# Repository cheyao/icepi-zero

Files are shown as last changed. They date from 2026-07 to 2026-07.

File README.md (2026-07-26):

# Icepi Zero - The portable FPGA development board



| Get your own on: | [**Crowd Supply**](https://www.crowdsupply.com/icy-electronics/icepi-zero) | [**Elecrow**](https://www.elecrow.com/icepi-zero.html) |
| --- | --- | --- |

If you are a student/educational institute, send me an email at `cyao _at_ duck.com` and I'll give an educational discount of $65!

We also got a [Discord server](https://discord.gg/vzrqfhcvWr)! Feel free to ask any questions here.

## What is the Icepi Zero?

The Icepi Zero is an FPGA development board in the popular Raspberry Pi Zero form factor. It carries a Lattice ECP5 25F, enabling powerful designs while keeping a small portable size. It also has a GPDI mini (General Purpose Display Interface, same as the one on the Pi Zero) port allowing easy digital video output.



## Why Icepi Zero?

Currently most powerful FPGA boards on the market are expensive and bulky.

I've always wanted a low-cost portable FPGA with video output to make my own CPU, but there isn't any on the market.

The Icepi Zero aims to fix this. Carrying a powerful ECP5 FPGA on a small Raspberry Pi Zero form factor, it is the ultimate portable solution for FPGA development. Additionally packing a GPDI mini port and 3 USB-C ports, it allows interfacing with multiple external I/O devices.

Icepi Zero is for everyone: Students can use it to learn about the internals of modern processors. Gamers can use it to emulate old hardware. Programmers can use it to test their code on multiple architectures.


<sub>Oberon running on Icepi Zero</sub>

Icepi Zero also has an on-board USB to JTAG converter, so no external programmers are needed.

Moreover Icepi Zero is fully open-source, no strings attached. Learn from the design! ([OSHWA cerified FR000026](https://certification.oshwa.org/fr000026.html)).



## Features

- Raspberry Pi Zero form factor
- Lattice ECP5U FPGA:
    - 24k LUT
    - 112 KiB of RAM
- One MiniGPDI connector (it's HDM- but I don't have the money to buy a license...)
- Three USB-C Ports
- 256Mbit 166MHz SDRAM
- MicroSD card slot
- On-board USB to JTAG and UART converter
- 50MHz external oscillator
- 128 Mbit of flash
- 4 user LEDs
- 2 user buttons

This powerful configuration allows the PCB to be used in numerous ways, including real time video processing, hardware AI acceleration and prototyping of ASICs. 

## Emulation

Over the course of multiple weeks, multiple emulation cores have been ported over, such as the [Oberon](https://github.com/cheyao/oberon), [Apple I](https://github.com/cheyao/apple-one) and the [Acorn Atom](https://github.com/cheyao/acorn_atom)! The Icepi Zero allows you to take cycle accurate replicas of your favourite systems in your pocket.


<sub>Apple I running on the Icepi</sub>


<sub>Acorn Atom running on the Icepi</sub>

## Learning

It is also supported by icestudio (custom fork: https://github.com/cheyao/icestudio), allowing easy access for beginners.



## Usage

Check out the `gateware` folder for example code and compilation instructions!

If you want to order this board, it uses a 1.2mm/1.6mm PCB with JLC04121H-7628 Stackup. Gerbers are in the `production` folder in the `hardware` directory.

For the PCB, the smallest component size is 0201 for 27 Ohm resistors on the USB-C datalines. But if you want only 0402 components, just delete those 0201 resistors and you will be fine.

NOTE: If you fabbed v1.1 before 01/06, the pins of the USB pullups and LED0 is different - check your gerbers.



[View PCB online](https://kicanvas.org/?github=https%3A%2F%2Fgithub.com%2Fcheyao%2Ficepi-zero%2Ftree%2Fmain%2Fhardware%2Fv1.2)

## Acknowledgments

This project was inspired by the [ulx3s](https://github.com/emard/ulx3s), huge props to the ulx3s team for making such a good board!

## Contact

If there is any questions DM `cyao.` or join the [discord server](https://discord.gg/vzrqfhcvWr)! Feel free to ask any questions here. Mail is also accepted at `cyao _at_ duck.com`. :)

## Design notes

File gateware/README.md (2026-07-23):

# Icedev Zero Firmware

## Table of Contents
- [Toolchain Setup](#toolchain-setup)
    - [Open Source Toolchain](#option-1-open-source-toolchain)
    - [Lattice Diamond](#option-2-lattice-diamond-ide)
- [Building Demos](#how-to-build-the-demos)
- [Flashing board](#how-to-flash)
- [Pinout](#pinout)
- [Linux on Litex SoC](#litex-soc)
- [More resources](#other-examples)

Welcome to the firmware folder! You can find numerous examples here:

- `blinky`: Classic LED counter!
- `counter`: Counter using the button as input :D
- `uart`: Uart transmission example
- `dvi`: GPDI example
- `usb`: USB examples
    - `usbmouse`: Shows a GPDI screen with an controllable mouse
- `third-party`: Third party verilog code
    - `memtest`: Memory tester w/ hdmi output! Pressing the button increases skew, middle row displays memory test cout, bottom row displays the number of bad memory reads.

## Toolchain setup

### Option 1: Open source toolchain

Download the latest build of the [OSS CAD Suite](https://github.com/YosysHQ/oss-cad-suite-build/releases/).

Unzip it anywhere and set shell command search path:
```
Linux              : export PATH=[path-to-bin]:$PATH
MacOS              : export PATH=[path-to-bin]:$PATH
Windows Powershell : $ENV:PATH = "[path-to-bin];" + $ENV:PATH
Windows cmd.exe    : PATH=[path-to-bin];%PATH%
```

### Option 2: Lattice Diamond IDE

To use the Diamond IDE, you must first request a license. (Free for individuals.)

Go to the [licensing page](https://www.latticesemi.com/Support/Licensing/DiamondAndiCEcube2SoftwareLicensing/DiamondFree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) and create an account. Then copy your device's MAC address, remove all colons and enter it into the "Host NIC" field. Click "Generate License". You should receive a license in your email after a few minutes.

After that, go to Diamond IDE's [download page](https://www.latticesemi.com/LatticeDiamond), install it following their instructions and select the license file when prompted.

You can now use Diamon IDE to create programs and flash it onto your Icepi with openFPGALoader!

Read more detailed instructions in the `DIAMOND.md` file.

## How to build the demos

Just `cd` into the directories, and type `make`!

- `make` runs `make debug`
- `make debug` installs the program to chip (bitstream is lost on power loss)
- `make install` installs the program to flash (bitstream is retained on power loss)
- `make install-bitstream` installs the `bitstream.bit` file to flash without rebuilding
- `make build` builds the bitstream (bitstream is retained on power loss)
- `make clean` deletes all the temporary files

## Make your own!

Just copy the `icepi-zero.lpf` and `Makefile` to the root of your directory, call your main module `top`, and you are good to go!

## How to flash

---
> An example bitstream file exists in the [documentation](../documentation/) folder.

There are two ways of using openFPGALoader to flash the board. The first one is via the command line, second via webusb on a browser.

#### Command Line

The following command is used to flash the development board

```zsh
openFPGALoader -cft231X --pins=7:3:5:6 bitstream.bit
```

You can also add the `--write-flash` flag to permanantly write the bitstream to flash, this way the bitstream file will be saved even when the board powers down.

Note: If you use the newest version of openFPGALoader, it supports the `-b icepi-zero` flag that can replace `-cft231X --pins=7:3:5:6`.

#### Browser

Alternatively, you can use the web version of openFPGALoader on Chrome: [https://ofl.trabucayre.com/](https://ofl.trabucayre.com/). (It won't work on Firefox as webusb is only supported by Chrome)

If you are on Windows, you must first install [Zadig](https://zadig.akeo.ie/), and change the USB driver for the FTDI chip to WinUSB: (Not needed on Linux)

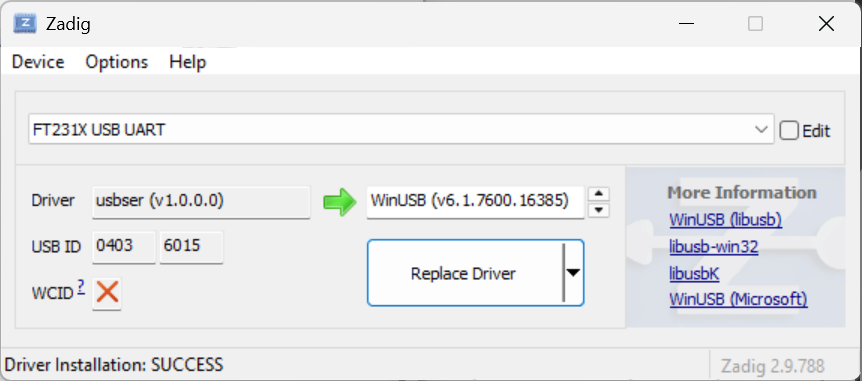
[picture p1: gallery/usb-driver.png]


Then, open the webpage and select "Default" as the cable and "icepi-zero" as the board, upload your .bit file and press Program.



Then select "FT231X USB UART" from the popup menu:



Now your board should be flashed! Happy hacking.

> Getting an error when flasing? Check out the [openFPGALoader troubleshooting](https://trabucayre.github.io/openFPGALoader/guide/troubleshooting.html) page.

## Pinout

The GPIO pinout is exactly the same as a [Pi Zero](https://pinout.xyz/):



You can find the name of rest of the I/O pins in `icepi-zero.lpf`:

- `gpio[27:0]`: gpio pins
- `led[4:0]`: User LEDs
- `button`: User button
- `gpdi_dp[3:0]`: GPDI interface
- `sdram_*`: SDRam interface
- `flash_*`: Flash interface
- `sd_*`: SDCard interface
- `usb_*`: FTDI/USB ports (UART/USB)
- `tp[1:0]`: Test points

Debug pins are distrubuted as the follwing picture shows:



## LiteX SoC

You can run a VexRiscv CPU (and Linux) on the Icepi Zero using [Litex](https://github.com/enjoy-digital/litex), @oliver408i wrote an [awesome guide](https://github.com/oliver408i/icepi-zero-litex) on how to use it!

## Other examples

This board is already supported by [apio](https://github.com/FPGAwars/apio/) and [icestudio](https://github.com/FPGAwars/icestudio)'s development branch. The board should be supported on stable in the next release.

The [litex-boards](https://github.com/litex-hub/litex-boards) also supports the Icepi Zero, while [linux-on-litex-vexriscv](https://github.com/litex-hub/linux-on-litex-vexriscv) has an pr open. (Forgot to open it last month, opps!)

For 1024x600 60Hz video output with audio, check out @danodus's awesome implementation: [https://github.com/danodus/ecp5_hdmi_audio_video](https://github.com/danodus/ecp5_hdmi_audio_video)

And here are some retro ports:

- [Commodore 64](https://github.com/m1nl/icepi-zero-c64) by @m1nl
- [Oberon](https://github.com/cheyao/oberon)
- [Port of Acorn Atom](https://github.com/cheyao/acorn_atom)
- [Apple 1 Emulator](https://github.com/alangarf/apple-one)
- [Sega Master System](https://github.com/cheyao/sega-sms)
- [Port of Silice](https://github.com/sylefeb/Silice/) (Check out the projects folder - it's full of interesting programs)
- [NES](https://github.com/m1nl/icepi-zero-nes/) implemented by [@m1nl](https://github.com/m1nl)

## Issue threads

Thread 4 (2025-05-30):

Hardware version 1.1 shows 1.0 on the silkscreen

cdwijs, 2025-05-30:
I've opened icepi-zero/hardware/v1.1/icepi-zero.kicad_pro in kicad:

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

In the 3d viewer, I see v1.0. That should have been v1.1:

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

cheyao, 2025-05-30:
Fixed!

Closed 2025-05-30.

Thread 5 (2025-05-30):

Testpins are not labeled

cdwijs, 2025-05-30:
On the back of the PCB, there are testpins. These are not labeled on the silkscreen:

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

They are documented in the names of the PCB traces:

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

Can the testpin names be added to the silkscreen?
Is this something to add to the readme?

cheyao, 2025-05-30:
I'd prefer to keep them unlabeled, since it'll be ugly and well testpoints are for testing purposes and you will already have the project open.

cdwijs, 2025-06-01:
I agree it can be ugly on the silkscreen itself.
I don't agree I already have the project open in all use cases. It would be nice if I can see the location of the test pins without having to run KiCad. When the two screenshots I've posted are added to a readme.md, I only need a web browser, so I can check it on a phone or tablet.

cheyao, 2025-06-01:
Oh right! I didn't see that they were marked on the pictures. I'll add them to the readme in the firmware directory soon

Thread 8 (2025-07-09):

Same iBom for all versions

Menkveld-24, 2025-07-09:
Hey as I was assembling I noticed that the iBom for all versions is the same (v1.0)

cheyao, 2025-07-09:
Oh that's my bad! I haven't re-generated the iboms since forever because I never used them :P

I'll just regenerated them all. There shouldn't be any big changes though - in between versions noramly only 1-2 connections are changed, but they force me to bump up the version number.

PS. If you ordered v1.3, I haven't added the lpf yet - the only change is that pin M1 and M2 is swapped. I am still not sure if this was needed and I am currently emailing with Lattice

Closed 2025-07-18.

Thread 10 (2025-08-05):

Is it possible to add a highspeed interface such as USB ULPI?

long-pham, 2025-08-05:
I suggest adding a highspeed interface such as:
- USB3343
- USB 3.0 with SerDes supported by Luna
- pcie if possible

cheyao, 2025-08-06:
Great ideas! I've looked into these a bit and I must say that PCIe would be impossible, because there isn't any place for such a connector on the pcb ;p

USB 3.0 (Assuming you are referring to SS) is equally not possible, since there isn't any space for a 3.0 connector :<

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

I'll have a look to the USB3343 though! Maybe I'll find somewhere to fit one :)

Closed 2025-08-17.

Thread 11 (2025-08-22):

Some sugestions for icepi-zero

goran-mahovlic, 2025-08-22:
Hi cheyao,

I have noticed you have lunched campaign and it looks it will be quite successful one!
So I wanted to congratulate you! You have really nice looking board there.

I really hope you will be able to produce those boards and get at least something out of it as from my perspective it is bit under priced for CS.

ECP is sometimes hard to get, but sometimes like now on LCSC there are limited number of ECP5 available for lower price.
I am mostly buying from Mouser or directly from Lattice over Arrow.
I always check ECP5 price on Octopart and get some average from verified sellers.
There is always marker in CN that offers discounted ECP5 but most of them are recycled and that is good, but then you need to count that some will not work.

In any way did not contact you abut that, but I have noticed few things that I can explain and you missed copy from ULX3S.

First is that ECP5 had some rules about power supply starting, and that can be really bad if not respected.
Like it can no boot, but it can enter in some strange mode and heath like crazy, and eventually die!

That is why emard added 100pF to the power supply's - power up sequence is in datasheet so make sure you read it and try to adjust it as you may face problems when many boards are produced and that will be late to fix.
You can always have at least placeholder for that cap that is doing ramp up.

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

Second is that We added I2C and some pins as we tough we could get HDMI IN - but that never happened.
So we do not even use that I2C chip - it is useful if you want to ask monitor what resolutions does support, but we mostly so not do that we just push picture out...

Zener diode is needed here as if you do not have it you will get 5V on this pin that goes into ECP5 and that is not good.

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

And one more
In my opinion your your 400mA inductors will not be adequate - specially for 3.3V and for other voltages you will need to check maximum current ECP5 will drain once you get bigger design inside.

And for 3.3V you need to calculate ECP5 all logic that works on 3.3V but also on people that will put some logic on HAT and use 3.3V if available.

In my designs I like to avoid using GND layers for Signal - but I see you are using them for JTAG that is not used often so it will probably be fine.

I think for now that is all I have noticed if I find more will let you know.

I am mostly available on Radiona discord so feel free to join -> https://discord.gg/S2CVqWMC5E

Best luck in delivering your boards to the public, and if you will need more help in porting something let me know..

Goran
